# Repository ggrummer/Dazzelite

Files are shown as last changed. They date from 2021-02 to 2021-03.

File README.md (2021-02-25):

# Dazzelite
Dazzelite is an easy to build project that uses a ring of tri-color LED lights, controlled by an FPGA, using a few simple instructions, to create different patterns of light. It can be built on a breadboard or in a beautiful case.

A video introduction can be seen at the following link:
https://vimeo.com/516437596

The "Documents" directory contains all the guides for building and using Dazzelite.

The "Dazz12" directory contains all the FPGA code.

The "EAGLE" directory contains the schematic, parts list and board design.

The "BreadBoardSchematic" contains the schematic for a simple breadboard version.

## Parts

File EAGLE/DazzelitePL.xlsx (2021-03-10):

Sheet: Main Assy
Dazzelite Mechanical Assembly
Description | Qty | Manufacturer | Part Number | Distributer | Cost
Neopixel Ring 24 LEDs | 1 | Adafruit | 1586 | Digi-Key | 16.95
Case | 1 | Serpac | 232C,BK | Digi-Key | 12.63
Supports for Ring | 4 | Essentra | SP1-12-01 | Digi-Key | 2.32
9V Battery Connector | 1 | Keystone | 235-M | Digi-Key | 0.74
9V Battery | 1 | Any |  |  | 2.00 | Approximate
Screws, #4 x 1/4" | 4 | Serpac | 6004 | Digi-Key | 1.36
PCB Bare | 1 |  |  |  | 13.00 | Approximate
PCB Parts | 1 |  |  |  | 33.53
Total |  |  |  |  | 82.53

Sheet: PCB Parts
Dazzelite PCB Parts With Upduino Rev 3.0 Board and Other Components
Description | Ref Des | Qty | Manufacturer | Part Number | Distributer | Cost
Cap 0.1uF, 50V X7R, Radial | C1, C4, C5 | 3 | Kemet | C326C104K5R5TA | Digi-Key | 0.66
Cap 100uF, 25V, Alum, Radial | C2, C3 | 2 | Kemet | ESK107M025AE3AA | Digi-Key | 0.40
Diode, Schottky, Axial, 1A, 20V | D1 | 1 | MCC | 1N5817-TP | Digi-Key | 0.32
DC/DC-Converter 5V, 1A, SIP3 | DC1 | 1 | Traco Power | TSR 1-2450 | Digi-Key | 6.14
Res 36K, 1%, 1/4W, Mini | R1 | 1 | Stackpole | RNMF14FTC36K0 | Digi-Key | 0.10
Res 62K, 1%, 1/4W, Mini | R2 | 1 | Stackpole | RNMF14FTC62K0 | Digi-Key | 0.10
Switch, Pushbutton | S1 | 2 | TE | 1-1825027-1 | Digi-Key | 0.52
Switch, Slide, SPDT | S2 | 1 | E-Switch | EG2219 | Digi-Key | 0.89
Lattice iCE40UP5K FPGA Board | U1 | 1 | TinyVision | Upduino-V3.0 | Tindie | 24.00
Quad Bus Buffer, DIL14 | U2 | 1 | TI | SN74AHCT125N | Digi-Key | 0.40
Total |  |  |  |  |  | 33.53

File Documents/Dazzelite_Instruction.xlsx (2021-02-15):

Dazzelite Instruction Creator |  |  |  | Rev 0.1
By: Grant Grummer
Command | 1 | See below | One Byte
Address/Duration/Loops | 8 | See below | 6/8/8 Bits
Brightness/Qty/Control | 0 | See below | One Byte
Blue | 0 | 15 max | One Nibble
Green | 0 | 15 max | One Nibble
Red | 0 | 15 max | One Nibble
RF Instruction |  | 10800000 | 32 Bits
 | [31:28] | [27:20] | [19:12] | [11:0]
Instruction Description | Command Number | Address/Duration/ Loops/Hours On | Brightness/Qty/Hours Off/ Control | Color/Hours Delayed
Blackout display | 0
Delay 1 | 1 | Duration, 255 max, 0 is a random delay
Finish 3 | 2
Set one lite with random address and/or color | 3 | Address = 0 to 63, random = 64 | Brightness | Red=0 current
 |  |  |  | Red=1 new 4
Set one lite | 4 | Address, 0 to 63 | Brightness | Color
Chase (lites rap around) | 5 | Offset size [25:20] 2 | 0 = decrement lite offset,
 |  |  | 1 = increment lite offset,
 |  |  | 2 = zero lite offset
Left to right & right to left | 6 | Qty of lites [22:20] 6 | Brightness
Fade in & out | 7 | Lower Limit [25:24] | 0 = disable fading,
 |  | Upper Limit [23:22] | 1 = enable fading
 |  | Speed Up [21:20]
Loop the last x number of commands | 8 | Number of loops, 255 for infinite loop | Qty of commands = loop command line number - start command number. 255 max commands.
Set random color palette | 9 | Color number 0 to 15 |  | Color
Reserved | 10
Rainbow colors | 11 |  | 0 = disable
 |  |  | 1 = enable
 | 12
Auto Timeout 5 | 13 | Hours on: 31 max, 0 always on (default) | Hours off: 31 max, 0 once off stay off (default) | Hours delayed (off): 31 Max, 0 (default)
 | 14
 | 15
 |  | [11:8] | [7:4] | [3:0]
Colors In Instructions 4 & 9 |  | Blue | Green | Red
Notes
1 | Duration: | 255 max times = 5.12 mSeconds, A duration of 8 is fast
2 | For backwards compatability, an offset size of 0 = 1. All others = number entered
3 | All instruction sets must end with a finish command
4 | Uses random color palette in instruction 9
5 | Setup before issuing the display instruction set
6 | 1 to 8 lites per side

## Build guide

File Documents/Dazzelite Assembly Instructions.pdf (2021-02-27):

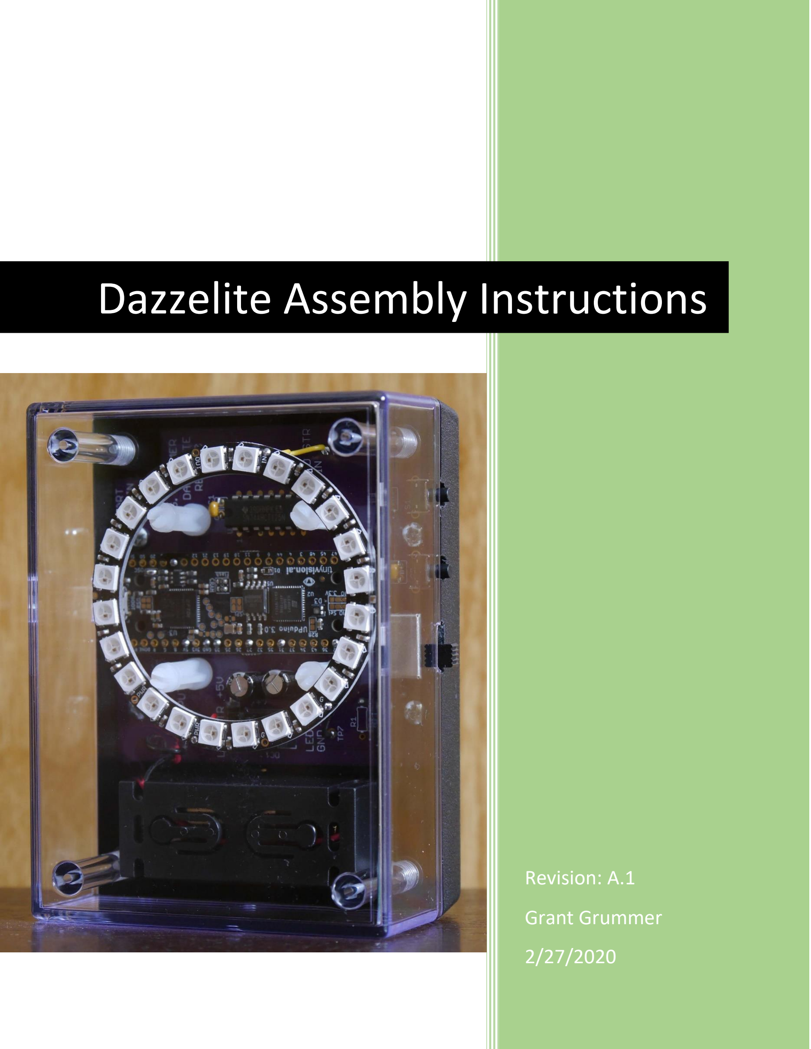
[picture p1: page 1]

## Grant Grummer

2/27/2020

# Dazzelite Assembly Instructions

## Revision: A.1

## Dazzelite Assembly Instructions

## Table of Contents

## Introduction

These instructions cover how to build a Dazzelite using a custom PCB installed into a beautiful case. The case (listed in the DazzelitePL spreadsheet parts list) has a plastic transparent top and an opaque bottom. It is assumed that all the parts, listed in the Dazzelite parts list, have been acquired before starting this assembly process.

## Tools required

The following list of tools are needed to build a Dazzelite:

- Soldering iron
- Solder
- Drill
- 3/16” drill bit (an optional small ~3/32” bit is helpful for drilling a pilot hole first)
- Philips screwdriver, #1
- Masking tape (optional but highly recommended)
- Wire cutters/strippers
- Small pliers
- Hobby knife (like an X-Acto knife)

## PCB Assembly Instructions

Only through hole parts are used in Dazzelite in order to make the PCB assembly easy to construct.

1. The UPduino board will need to be reworked before it can be used. It’s easier to do this rework before installing it onto the Dazzelite PCB. The rework involves the following two steps.
a. Apply a blob of solder across the OSC solder jumper
b. Highly recommend desoldering and removing LED D1. It distracts from the ring display.

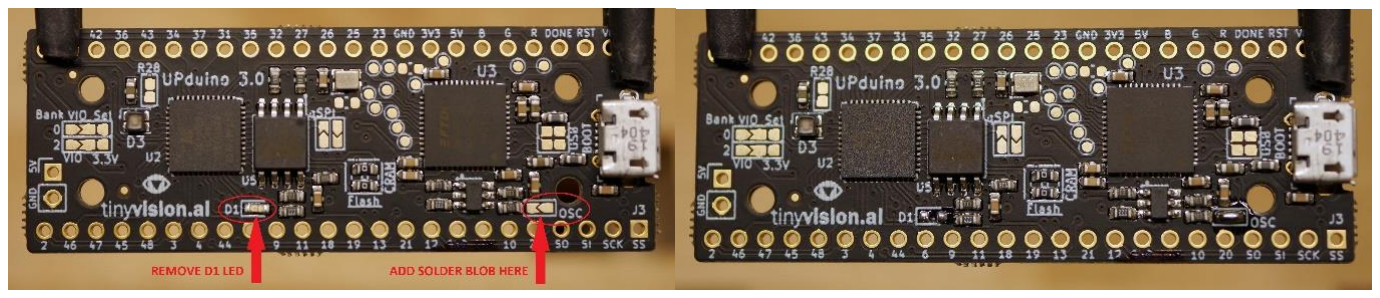
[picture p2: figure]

2. Insert the supports for the LED ring after all components have been soldered to the PCB
3. Break off 2 sets of 2 pins from the headers supplied with the UPduino
a. One set is used to for the 5V and GND pins furthest from the USB connector
b. The second set is used for TP3 and TP4 on the PCB
4. Place the headers on the PCB and the UPduino on the headers
a. None of the 8 pins on either side furthest from the USB connector, need to be connected to the PCB
b. All the other pins on the UPduino do not need to be soldered to the PCB (refer to schematic), but they can if desired.
c. All 5V and GND pins should be soldered to the PCB (including the ones furthest from the USB connector)
5. Solder all components to the component side of the PCB, except the LED ring which is placed above the PCB on supports (in the following steps)

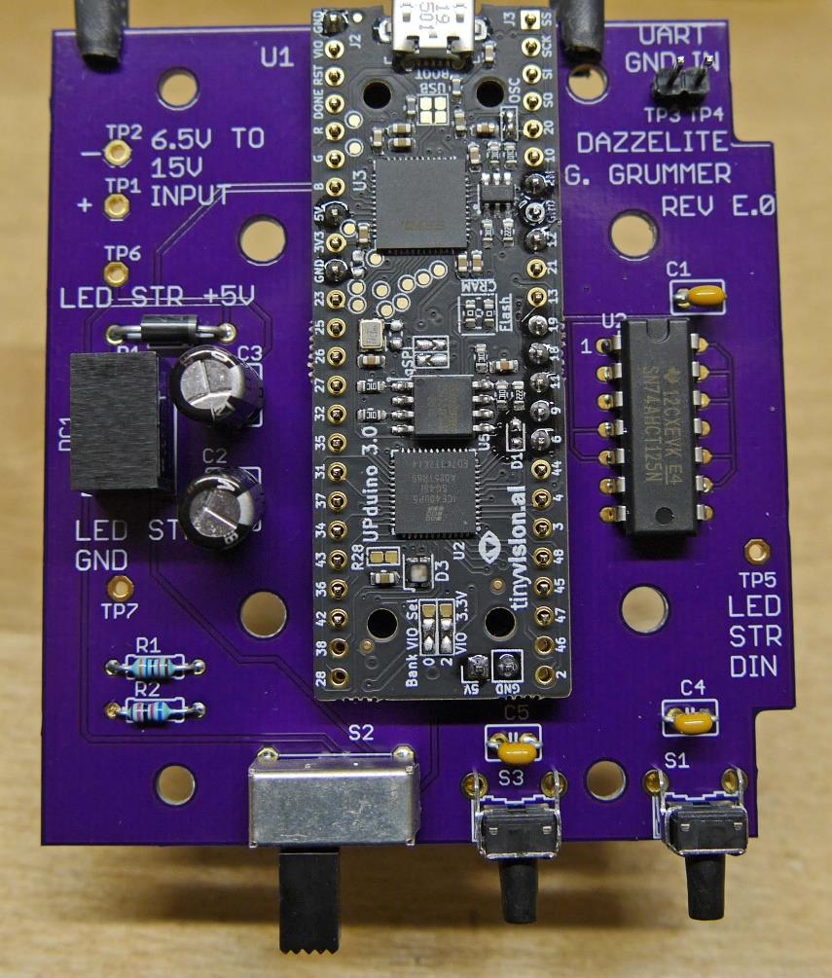
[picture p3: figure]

6. Rotate the LED ring so that the “IN” and “OUT” holes on the ring are the same distance to the edge of the PCB
7. Place ring onto the supports

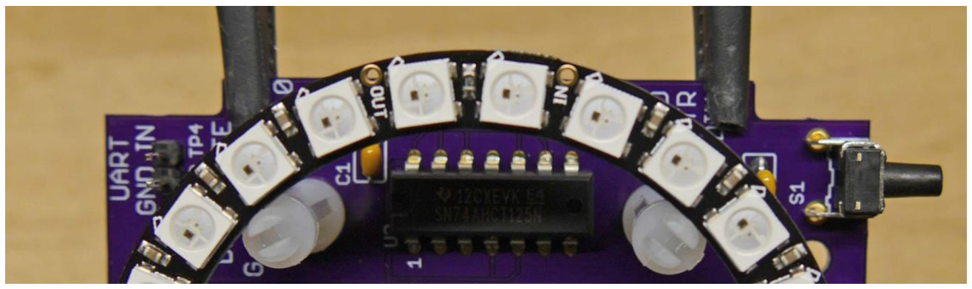
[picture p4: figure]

8. Solder the following 1-inch long wires from PCB to ring
a. TP5 on the PCB to IN on the ring
b. TP6 on the PCB to PWR on the ring
c. TP7 on the PCB to G on the ring
9. Do not attach the battery wires yet, it will be done in a later section

## Case Cutouts

These instructions are from the prospective of the 9V battery part of case up and looking into the case. The cutout for the USB is on the right side and the cutouts for the switches are on the left side.

To avoid scratching the top (transparent) section, put masking tape on the outside of it. Cover the whole top and the top two thirds of the sides.

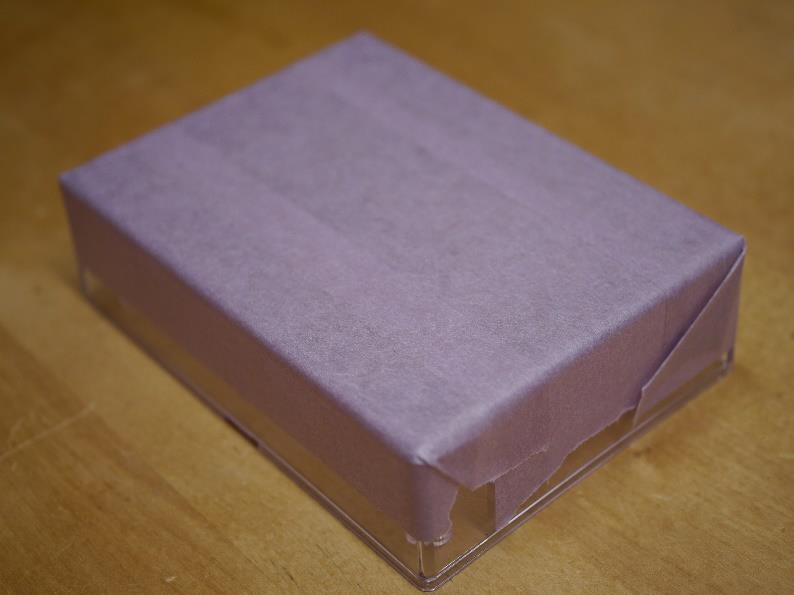
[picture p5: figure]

### Bottom (Opaque) Drilling and Cutouts

The top and bottom sections should not be attached.

All drill holes are located 5/8” from the bottom of the case.

The following table lists the locations of the drill holes from the side opposite the battery.

Part

From Case Side
Opposite Battery
S1 PB SW Location | 13/16
S3 PB SW Location | 1 & 7/16
S2 Slide SW Location | 1 & 15/16 and 2 & 3/16
USB Location | 1 & 5/8 and 1 & 13/16

Table 1: Drill Hole Locations

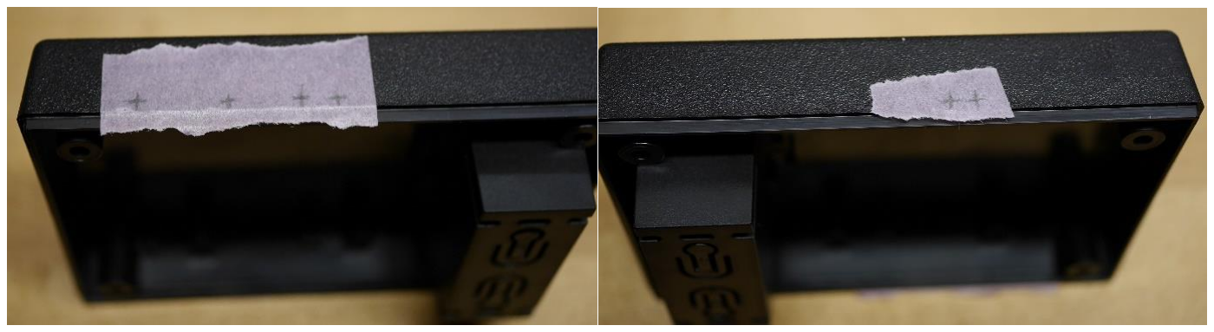
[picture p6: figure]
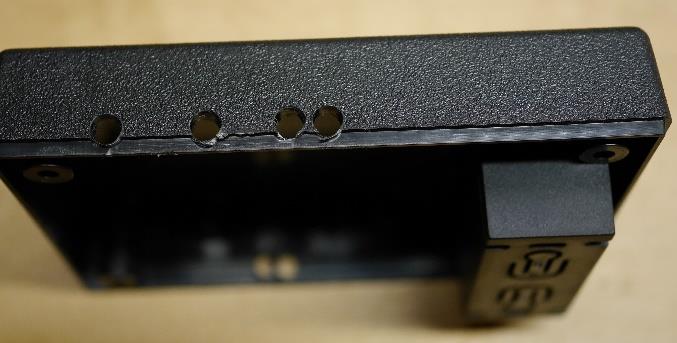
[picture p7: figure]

After the holes are drilled, make slots from the holes by cutting away the material from the side of the holes to the top on the bottom section of the case. Also cut away the material between the S2 (slide switch) holes and the USB holes.

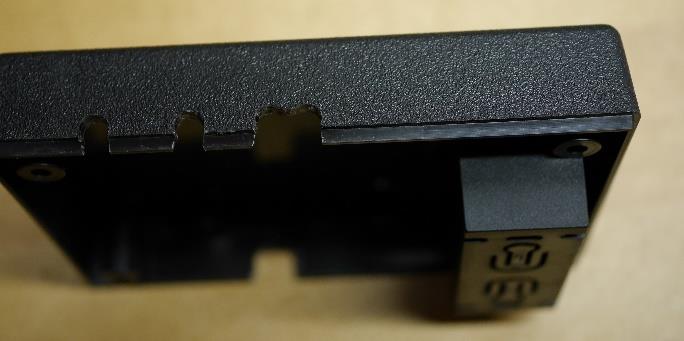
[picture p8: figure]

### Top (Transparent) Case S2 and USB Cutouts

Temporarily place the top and bottom sections together. The manufacturing plastic insertion dot side of the top section should align with the battery holder side of the case.

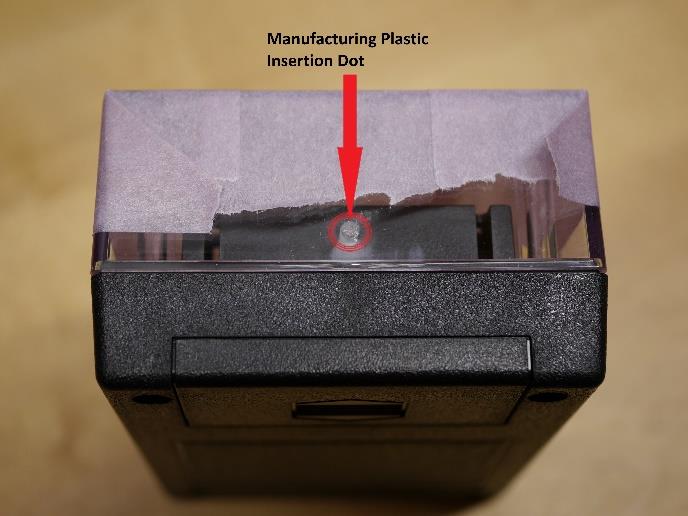
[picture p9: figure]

Mark (with the utility knife) where bottom section cutout for the S2 and USB cutouts meets the top section. There should now be 2 marks on each side. Separate the top and bottom sections. In each mark, cut down 0.1" to the thicker part of the top section. Cut away the thinner part (of the case) between the 2 marks on each side.

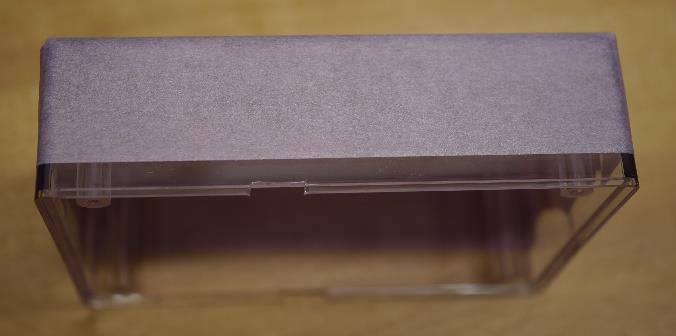
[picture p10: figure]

## Connecting Battery Wires

Temporary place the assembled PCB in the bottom section of the case. The battery wires go through the battery holder nearest to the “6.5V TO 15V INPUT” text on the PCB. The battery connector is placed at the opposite end of the battery holder.

Lift the assembled PCB so the battery wires can be soldered onto the board. The red (positive) wire connects to TP1 and the black (negative) wire connects to TP2.

## Assembly Note

Unfortunately, the UPduino board was built with the USB connector recessed into the PCB. This makes it difficult to access the connector through the case. So, just prior to screwing the PCB into the case, gently push the PCB towards the USB slot and hold it there. Now screw the board into the case. This helps get the USB connector closer to the case.

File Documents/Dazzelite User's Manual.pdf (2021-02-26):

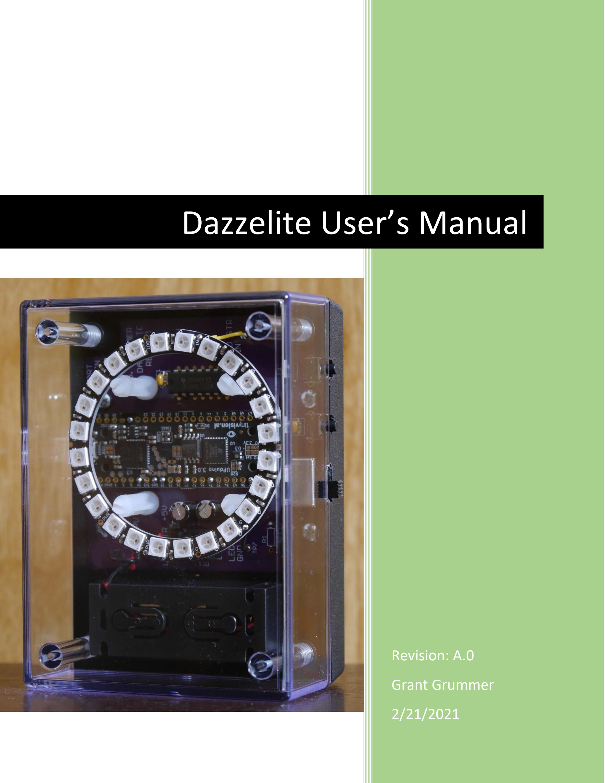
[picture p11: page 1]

## Grant Grummer

2/21/2021

# Dazzelite User’s Manual

## Revision: A.0

## Dazzelite User’s Manual

## Table of Contents

## Introduction

Welcome to the Dazzelite User’s Manual. Dazzelite can be built in many ways. One can build a version on a breadboard, a perfboard or a custom PCB. The perfboard and custom PCB versions can be mounted into a case, making the unit portable. This document is written for the custom PCB version, mounted into a beautiful, portable case with a built-in battery compartment.

Dazzelite uses a tri-color LED ring to produce different light displays. Dazzelite is programmable, so the displays are only limited by your imagination. No previous software knowledge is required. A set of default light displays along with an introduction to Dazzelite can be viewed at the following link:

https://vimeo.com/516437596

A small set of display specific instructions are used to create different display patterns. There are up to 16 possible instructions. Not all of these instructions are defined at the time of this writing. These are available for those who wish to augment the functionality of this project.

The design contains all the electronic hardware needed to drive the LED ring. The brain of the hardware is a Lattice iCE40 Ultra Plus 5K FPGA (Field Programmable Gate Array). It, along with programming and other support logic, is on the UPduino v3.0 (https://www.tindie.com/products/tinyvision_ai/upduino-v30-low-cost-lattice-ice40-fpga-board/?pt=ac_prod_search) low cost daughter board. It’s mounted onto the Dazzelite board. The Dazzelite board also contains switches, power supply and interface hardware. Dazzelite can be powered from the micro USB connector on the daughter board or an external source.

Dazzelite is controlled via three switches. The power slide switch enables/disables power from the external source or enables/disables the FPGA if powered from micro USB connector. The upper pushbutton switch selects one of four display pattern instruction sets. Each set can have up to 256 instructions. The lower pushbutton switch selects different brightness levels.

## Dazzelite Design Environment

In order to program Dazzelite, one must first setup a design environment. Refer to the “Dazzelite Installation and Setup” document for instruction on how to set it up. The rest of this document assumes this setup has been completed.

## Building the Design

The Lattice Radiant design environment is used to build the design. A full build is performed by clicking on the “Run All” triangle. The boxes to the right of the “Run All” triangle all turn green (with a check mark) once the design has been built. See Figure 1.

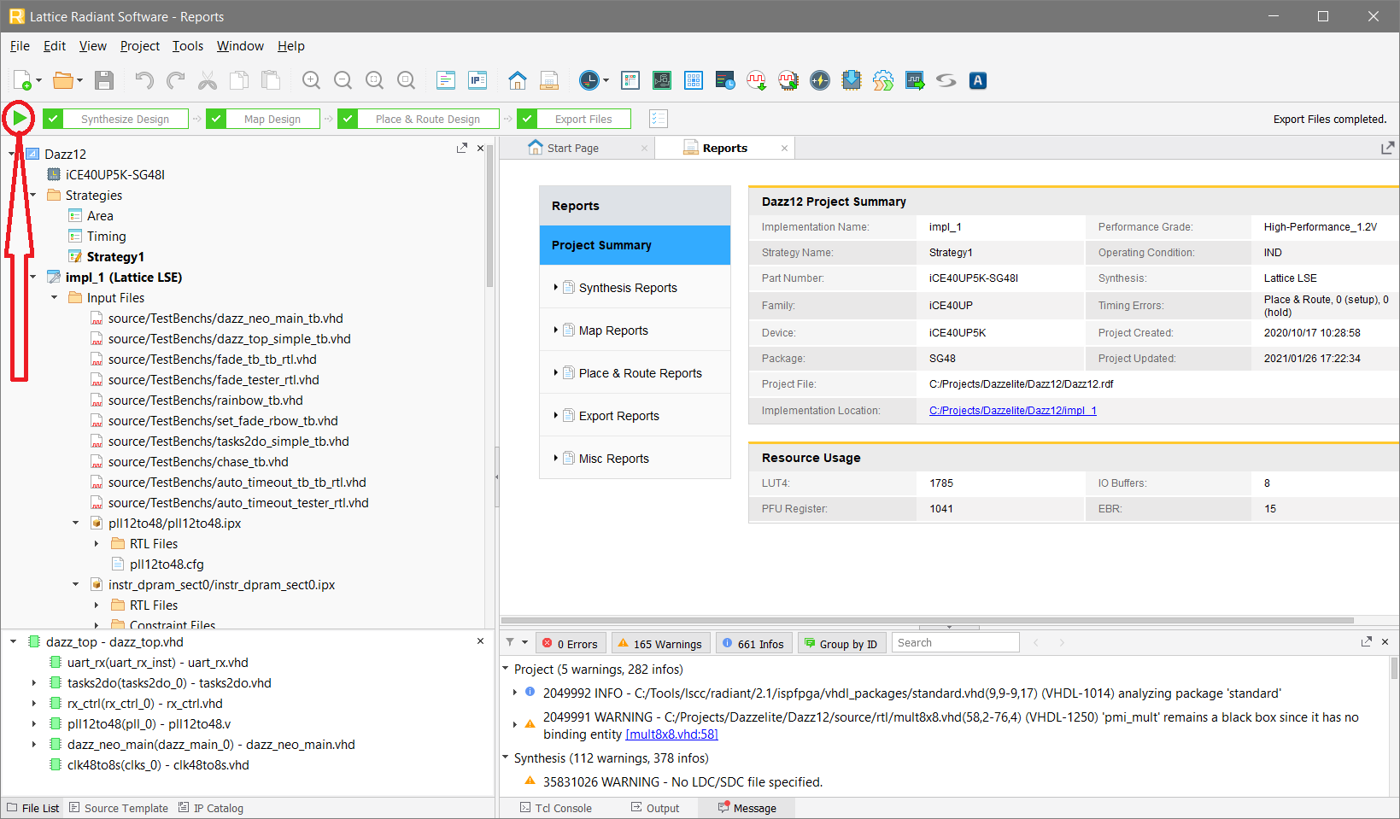
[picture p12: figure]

Figure 1: Run All

## Custom Displays

A great way to get started with making your own custom displays is to build new display instruction sets. One doesn’t need to know anything about FPGAs or software to do this. Use the supplied “Dazzelite_Instruction” spreadsheet to create each instruction. Use a text editor to combine the new instructions into a set of instructions. Refer to the supplied example display instruction sets, in the “Patterns” folder, to see how this looks. Remember to end each instruction set with the Finish instruction!

There are 4 memories in Dazzelite, each contain one display pattern. They are selected via the pattern pushbutton switch. Each memory can be loaded with a new pattern by double clicking on inst_dpram_sect0, 1, 2 or 3 as shown in Figure 2.

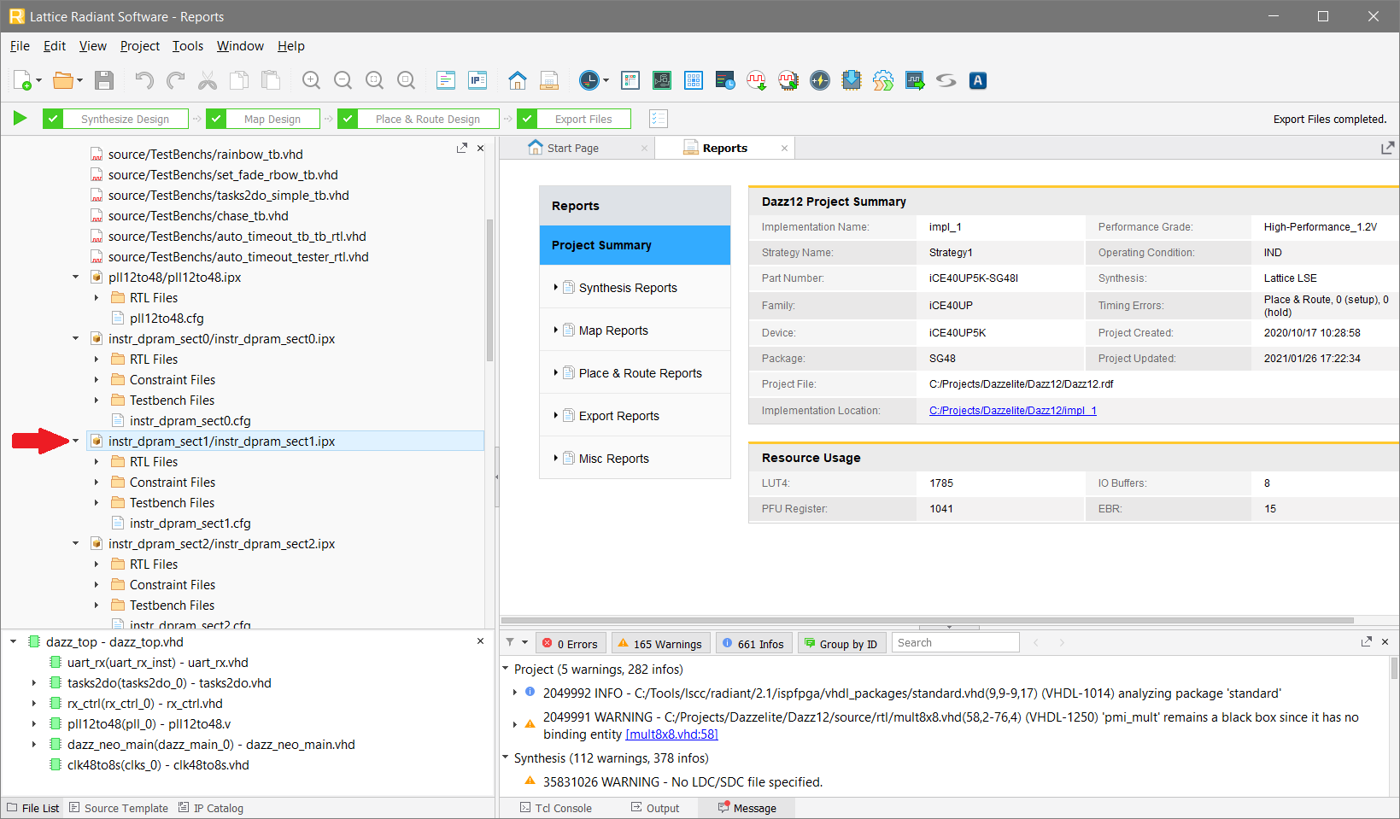
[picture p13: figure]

Figure 2: Changing Display Patterns

Replace the current instruction set with your new instruction set by clicking on “…” and navigating to that instruction as highlighted in Figure 3.

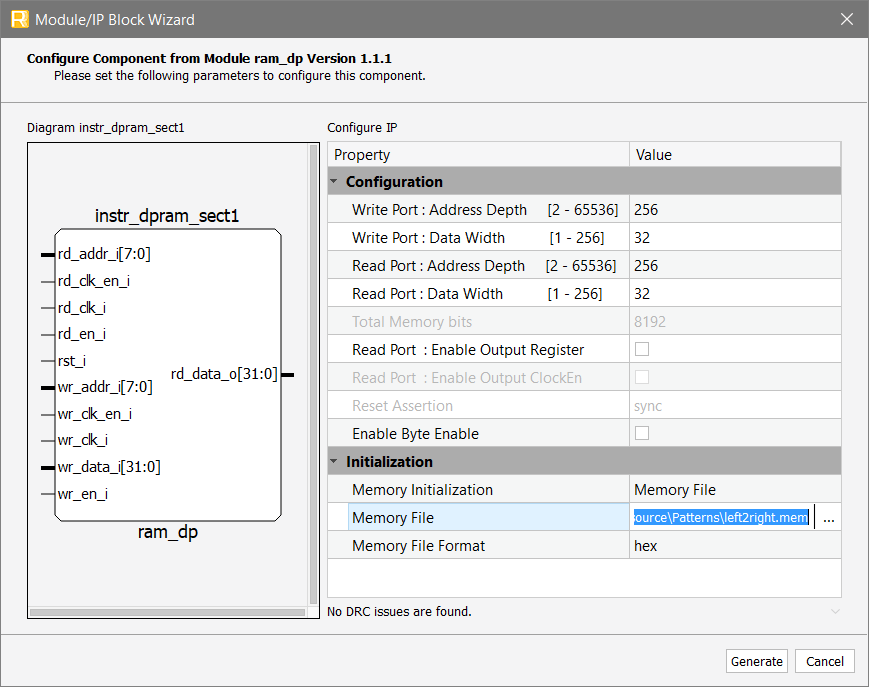
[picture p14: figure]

Figure 3: Replacing Display Pattern

Click in the “Generate” button (at the bottom of the window) to replace the display pattern. After that completes, re-build the design as outlined in the Building the Design section.

## Programming Dazzelite

Dazzelite can be programmed from the Radiant program or via a standalone programmer.

### Programmer Access Through Radiant

From Radiant, click on the programming icon as shown in Figure 4.

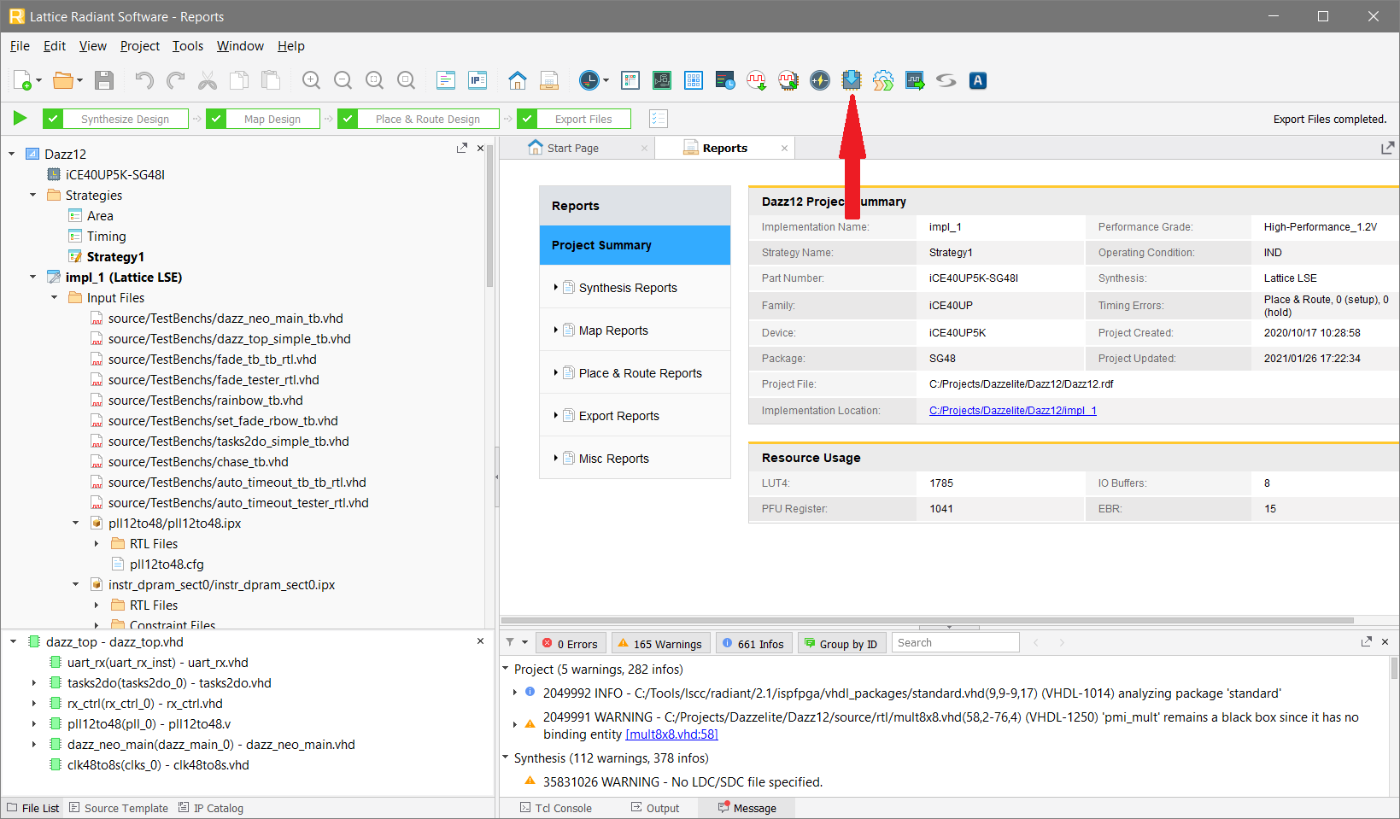
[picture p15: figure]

Figure 4: Programming Icon

### Standalone Programmers

There are many programmers that can be used to program Dazzelite. One is the Radiant Programmer Standalone (https://www.latticesemi.com/Products/DesignSoftwareAndIP/FPGAandLDS/Radiant) and another is the Diamond Programmer Standalone. (http://www.latticesemi.com/en/Products/DesignSoftwareAndIP/ProgrammingAndConfigurationSw/Programmer.aspx) They’re both very similar.

### Programming Steps

The following steps can be used with the Radiant Programmer (either via Radiant or standalone) to program Dazzelite. The Diamond Programmer steps may be slightly different.

1. Connect the micro USB port on the UPDuino v3.0 to your PC
2. Open the Radiant Programmer
3. Click `Detect Cable` then `OK`
4. After scanning, select `Generic JTAG Device` and `Select iCE40 UltraPlus`
5. Under `Device` click iCE40UP3K and change it to iCE40UP5K
6. Under `Operation` double click `Fast Program` and change `Target Memory: ` to `External SPI Flash Memory`
7. Select your `*.hex` programming file under `Programming file`.
8. Configure the following `SPI Flash Options`
a. Winbond
b. W25Q32JV
c. 208mil 8-pin SOIC
9. Click `Load from File` under `SPI Programming` to get load size
10. Click OK
11. Click `Run` -> `Program Device`

## Instructions

The Dazzelite_Instruction spreadsheet provides an easy way to create instructions. It allows instructions to be build using decimal number and automatically provides the hexadecimal value (of the instruction) needed by the FPGA. Optionally, a detailed look at each bit, in each instruction, is provided in the rest of this section.

As previously noted, there are up to 16 possible instructions. Some are specifically tailored for the RGB LED ring. Instructions are 32-bits long. All instructions start with a command. Some commands are followed by additional fields. A detailed description of each instruction is presented in the following sections. Note all bits of the instructions are zeroed at powerup unless otherwise noted.

### Instruction 0: Blackout Display

Blackouts the entire display.

31 | 28 | 27 | 0
CMD0 | Unused | Unused | Unused | Unused | Unused
Bits | Name | Function
[31:28] | CMD0 | Blackouts all the LEDs in the string(s). All bits must be zero.
[27:0] | Unused | Not defined

### Instruction 1: Delay

Adds a programmable time delay. Each additional count adds 5.12 mSeconds. The maximum count is 255 (0xFF). A count a zero creates a random delay.

31 | 28 | 27 | 20 | 19 | 0
CMD1 | DLY | Unused | Unused | Unused | Unused
Bits | Name | Function
[31:28] | CMD1 | Programmable delay. Value = 1
[27:20] | DLY | Delay count. Max = 255 (0xFF). All zeros create a random count.
[19:0] | Unused | Not defined

### Instruction 2: Finish

All instruction sets must end with a finish command!

31 | 28 | 27 | 0
CMD2 | Unused | Unused | Unused | Unused | Unused
Bits | Name | Function

[31:28] | CMD2 | Informs the FPGA that the present instruction set is finished. Value = 2
[27:0] | Unused | Not defined

### Instruction 3: Set Random LED

Used to set one LED at a random location/address and/or color. The random color is selected from the 16 colors in the color palette (see Instruction 9: Set Color Palette).

31 | 28 | 27|26| 25 | 20 | 19 | 12 | 11 | 1 | 0
CMD3 | U | R | | ADDR | BRITE | Unused | Unused | Unused|N
Bits | Name | Function
[31:28] | CMD3 | Sets one LED. Value = 3
[27] | U | Unused, not defined
[26] | R | Random LED address 0 = bits [25:0] specify address of LED 1 = random LED address generated
[25:20] | ADDR | Specific LED address when [26] = 0. Values 0 to 63 (0x3F)
[19:12] | BRITE | Set the brightness of the LED. Values 0 to 255 (0xFF)
[11:1] | Unused | Not defined
[0] | N | 0 = use the same color as used in the last CMD3. That color was the one last selected from the color palette. 1 = use the next color in the color palette.

### Instruction 4: Set LED

Used to set one LED’s address and color.

31 | 28 | 27 26 | 25 | 20 | 19 | 12 | 11 | 8 | 7 | 4 | 3 | 0
CMD4 | U | | ADDR | BRITE | BLUE | GREEN | RED
Bits | Name | Function
[31:28] | CMD4 | Sets one LED. Value = 4
[27:26] | U | Unused, not defined
[25:20] | ADDR | Specific LED address. Values 0 to 63 (0x3F)
[19:12 | BRITE | Set the brightness of the LED. Values 0 to 255 (0xFF)
[11:8] | BLUE | Sets the amount of blue. Value 0 to 15 (0xF)
[7:4] | GREEN | Sets the amount of green. Value 0 to 15 (0xF)
[3:0] | RED | Sets the amount of red. Value 0 to 15 (0xF)

### Instruction 5: Chase

Adds an offset to all LED addresses. Increments or decrements that address along with their brightness and color. The offset wraps around at maximum numbers of LEDs per string.

31 | 28 | 27 26 | 25 | 20 | 19 | 14|13|12 | 11 | 0
CMD5 | U | | SIZE | Unused | | Z | ID | Unused | Unused | Unused
Bits | Name | Function
[31:28] | CMD5 | Increments or decrements every LED’s address by the offset size. Value = 5
[27:26] | U | Not defined
[25:20] | SIZE | Offset size. A size of 0 = 1. All others = number entered
[19:14] | Unused | Not defined
[13] | Z | 0 = do not zero LEDs address offset 1 = zeros LEDs address offset (ID value ignored)
[12] | ID | 0 = decrement offset 1 = increment offset
[11:0] | Unused | Not defined

### Instruction 6: Left to Right and Right to Left

Two strings of colors start at the top of the display and make their way to the bottom then back up to the top. As they merge (at the bottom), They are added together and the resulting color is displayed.

31 | 28 | 27 | 23 | 22 | 20 | 19 | 12 | 11 | 0
CMD6 | Unused | | QTY | BRITE | Unused | Unused | Unused
Bits | Name | Function
[31:28] | CMD6 | Runs the algorithm. Value = 6
[27:23] | Unused | Not defined
[22:20] | QTY | Quantity of lights, 1 to 8 per side
[19:12] | BRITE | Set the brightness of the LED. Values 0 to 255 (0xFF)
[11:0] | Unused | Not defined

### Instruction 7: Fade In and Out

Fades all LEDs brightness. Increments and then decrements all LEDs brightness.

31 | 28 | 27 26|25 24|23 22|21 20 | 19 | 13|12 | 11 | 0
CMD7 | U | LLIM| ULIM| SPD | Unused | | EF | Unused | Unused | Unused
Bits | Name | Function
[31:28] | CMD7 | Increments or decrements every LED’s address by one. Value = 7
[27:26] | U | Unused, not defined
[25:24] | LLIM | Limits how low the brightness value can go
[23:22] | ULIM | Limits how high the brightness value can go
[21:20] | SPD | Speeds up the incrementing and decrementing
[19:13] | Unused | Not defined

[12] | EF | 0 = disable fading once decrement reaches its lowest value 1 = enables fading starting at its lowest value
[11:0] | Unused | Not defined

### Instruction 8: Loop

Loop the previous x number of instructions.

31 | 28 | 27 | 20 | 19 | 12 | 11 | 0
CMD8 | LOOPS | QTY | Unused | Unused | Unused
Bits | Name | Function
[31:28] | CMD8 | Repeats previous instructions. Value = 8
[27:20] | LOOPS | Sets the number of times a loop is executed. A value of 255 (0xFF) is a continuous loop.
[19:12] | QTY | Quantity of instruction to repeat. Subtract the start instruction from the loop instruction line number.
[11:0] | Unused | Not defined

### Instruction 9: Set Color Palette

Storage location for 16 definable colors. Used in conjunction with Instruction 3: Set Random LED. A set of predefined colors are loaded at powerup. Use this instruction to change them.

31 | 28 | 27 | 24 | 23 | 20 | 19 | 12 | 11 | 8 | 7 | 4 | 3 | 0
CMD9 | Unused | CNUM | Unused | BLUE | GREEN | RED
Bits | Name | Function
[31:28] | CMD9 | Sets one LED. Value = 9
[27:24] | Unused | Not defined
[23:20] | CNUM | Specific palette address. Values 0 to 15 (0xF)
[19:12] | Unused | Not defined
[11:8] | BLUE | Sets the amount of blue. Value 0 to 15 (0xF)
[7:4] | GREEN | Sets the amount of green. Value 0 to 15 (0xF)
[3:0] | RED | Sets the amount of red. Value 0 to 15 (0xF)

### Instruction 10 (0xA): Reserved

Do not use. It’s used in other versions of this project.

31 | 28 | 27 | 0
CMD10 | Unused | Unused | Unused | Unused | Unused
Bits | Name | Function
[31:28] | CMD10 | Reserved. Value = 10 (0xA)
[27:0] | Unused | Not defined

### Instruction 11 (0xB): Rainbow

Transitions through the 12-bit color spectrum.

31 | 28 | 27 | 13|12 | 11 | 0
CMD11 | Unused | Unused | |ER | Unused | Unused | Unused
Bits | Name | Function
[31:28] | CMD11 | Increments or decrements every LED’s address by one. Value = 11 (0xB)
[27:13] | Unused | Not defined
[12] | ER | 0 = disable the transitions 1 = enables the transitions
[11:0] | Unused | Not defined

### Instruction 12 (0xC): Reserved

Do not use. It’s used in other versions of this project.

31 | 28 | 27 | 0
CMD12 | Unused | Unused | Unused | Unused | Unused
Bits | Name | Function
[31:28] | CMD12 | Reserved. Value = 12 (0xC)
[27:0] | Unused | Not defined

### Instruction 13 (0xD): Automatic Timeout

Automatically turns the LEDs on and off according to the following settings. The instruction set in use before the time “off” will resume once the time “on” is attained. One should set this up before issuing display instructions.

31 | 28 | 27 | 25 | 24 | 20 | 19 | 17 | 16 | 12 | 11 | 5 | 4 | 0
CMD13 | Unused | | HON | Unused | | HOFF | Unused | Unused | HDLY
Bits | Name | Function
[31:28] | CMD13 | Sets one LED. Value = 13 (0xD)
[27:25] | Unused | Not defined
[24:20] | HON | Hours on. “0” is always on. Values 0 to 31 (0x1F)
[19:17] | Unused | Not defined
[16:12] | HOFF | Hours off. “0” is once off stay off. Value 0 to 31 (0x1F)
[11:5] | Unused | Not defined
[4:0] | HDLY | Hours delayed (off). Value 0 to 31 (0x1F)

### Instruction 14 (0xE): Unused

Available for a new instruction.

31 | 28 | 27 | 0
CMD14 | Unused | Unused | Unused | Unused | Unused
Bits | Name | Function
[31:28] | CMD14 | Unused but available. Value = 14 (0xE)
[27:0] | Unused | Not defined

### Instruction 15 (0xF): Unused

Available for a new instruction.

31 | 28 | 27 | 0
CMD15 | Unused | Unused | Unused | Unused | Unused
Bits | Name | Function
[31:28] | CMD15 | Unused but available. Value = 15 (0xF)
[27:0] | Unused | Not defined

## Code Base

The code base consists of mostly VHDL modules, some Verilog modules, instantiated and inferred IPs. There are 5 instantiated cores.

One instantiated core is a PLL (Phase Lock Loop). It’s used for creating a 48 MHz clock from the 12 MHz oscillator on the daughter board. A separate module divides the 48 MHz clock down to the 8 MHz and 800 kHz clocks used in the design. The majority of the design runs at 800 kHz.

The 4 remain cores are 256 x 32 memories. Each core holds an instruction set for a display pattern.

## Block Diagram of Dazzelite Code

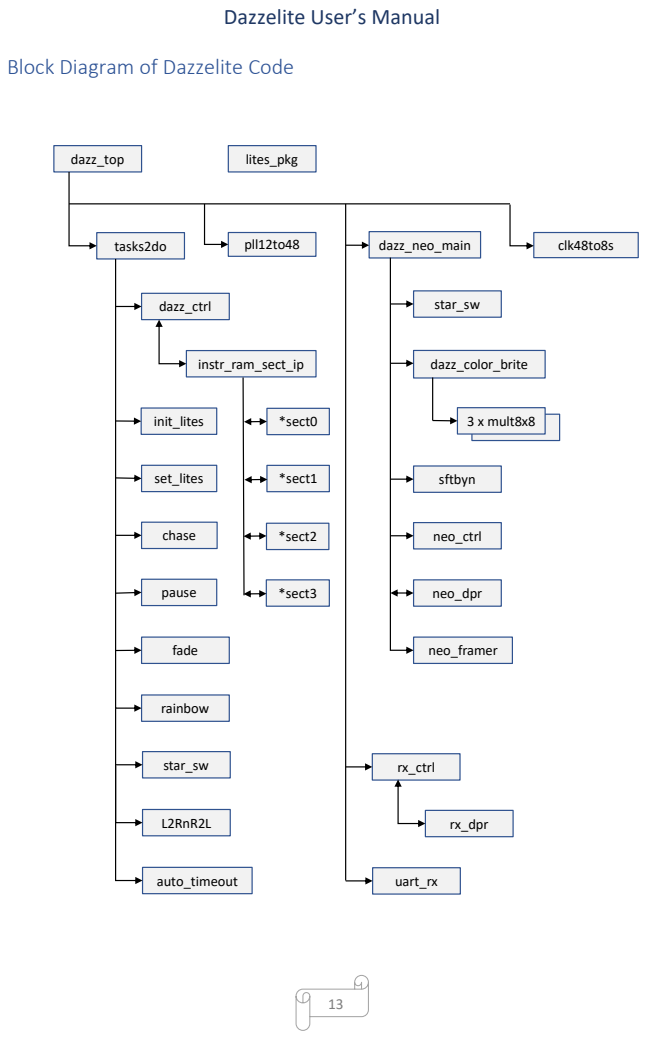
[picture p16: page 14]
chase; pause; fade; rainbow; set_lites; dazz_top; tasks2do; dazz_ctrl; instr_ram_sect_ip; init_lites; lites_pkg; pll12to48; dazz_neo_main; neo_ctrl; neo_dpr; neo_framer; uart_rx; star_sw; L2RnR2L; dazz_color_brite; 3 x mult8x8; auto_timeout; rx_ctrl; rx_dpr; sftbyn; clk48to8s; *sect0; *sect1; *sect2; *sect3

## UART

A UART can be used to temporarily download a new display pattern to Dazzelite. The pattern gets loaded into the first display’s memory. It’s remains in that memory until power is turned off.

The UART uses the following protocol.

- 9600 baud rate
- One start bit
- Eight hex data bits
- One stop bit

Each transfer consists of one bite. Four transfers are required to make one instruction. Multiple sets of four instructions, following each other, make up a Dazzelite instruction set.

The protocol has been used by an old Digi XBee wireless board. The newer boards “appear” to still support this protocol. This has not been tested with new boards.

By adding a wireless board to Dazzelite, one can use a remote wireless board to communicate with it. The UART pins are used to connect Dazzelite to the local wireless board. Digi’s XCTU software can be used with Digi XBee boards to remotely send a new display pattern.

Some UART programs support sending hex data, though it’s not common. These can be used to directly sent a new temporary display pattern to Dazzelite using a USB to serial (3.3V) cable.

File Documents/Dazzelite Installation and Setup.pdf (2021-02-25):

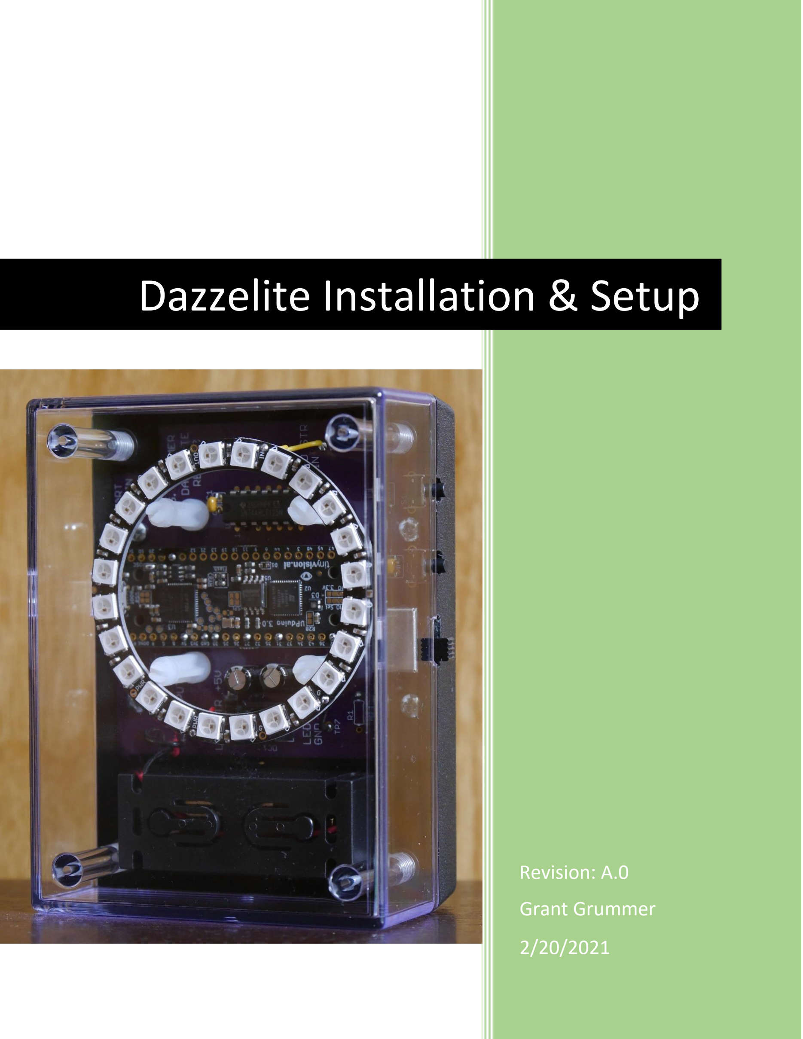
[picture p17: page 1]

## Grant Grummer

2/20/2021

# Dazzelite Installation & Setup

## Revision: A.0

## Dazzelite Installation & Setup

## Table of Contents

## Introduction

Welcome to the Dazzelite project setup. Whether you’re planning to build a version on a breadboard, a perfboard or a custom PCB, the follow information will help you on your way. This document covers Windows installations only.

## Installing Build Tools

The design was built using the Lattice Semiconductor Radiant platform. There are other tools one could use, but that would require significant changes to the supplied code. Radiant is free and is available on the Lattice website at:

http://www.latticesemi.com/Products/DesignSoftwareAndIP/FPGAandLDS/Radiant

You’ll find useful documentation on that web page. The Radiant Software Installation Guide document has important installation and license information. A license is required to run Radiant. The link to obtaining a license is also at the above website. Follow the license link. You’ll be asked to sign in to your account. If you don’t have one, you’ll need to create by selecting the “Create Account” link.

Once a license is obtained, download and install Radiant. When the “Select Component(s)” window opens, the only FPGA device you’ll need is the “Lattice iCE40UP”, though it’s ok to install more devices if desired.

## Download Dazzelite Files

The Dazzelite files are located in GitHub. In order to download the files, one clones the directories using “GitHub Desktop”. (https://desktop.github.com/) Once GitHub Desktop is installed, the Dazzelite project is located at:

https://github.com/ggrummer/Dazzelite

Place all the files and directories in a new directory. The design was built using the following root directory structure: “C:\Projects\Dazzelite”. It may be OK to use a different directory structure, but that hasn’t been tested.

## Building the Design for the First Time

Start the Radiant program. Double click on the “Open Project” icon. See Figure 1.

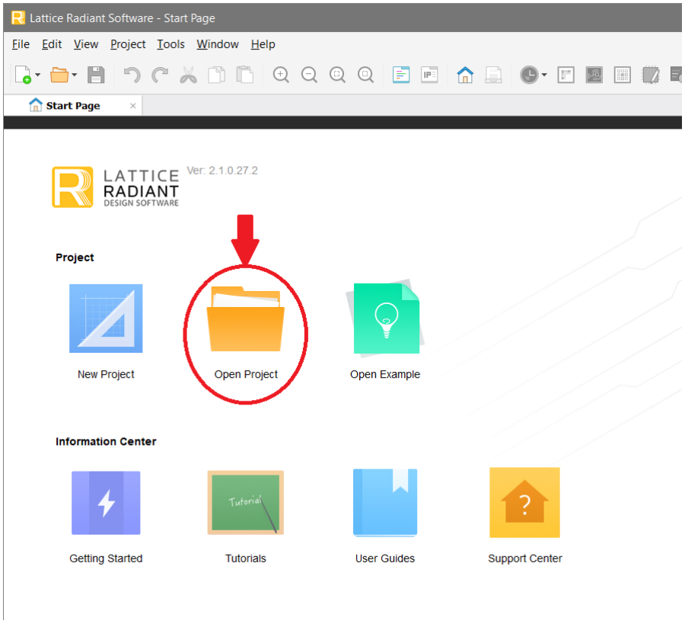
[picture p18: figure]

Figure 1: Open Project Window

Navigate to the “Dazz12” directory and select the “Dazz12.rdf” file. The Lattice Radiant Software main

window will open. Click on the “Run All” triangle. See Figure 2.


Figure 2: Lattice Radiant Software Window

The boxes to the right of the “Run All” triangle all turn green (with a check mark) once the design has been built.

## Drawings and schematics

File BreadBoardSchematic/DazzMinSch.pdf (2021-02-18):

A

A

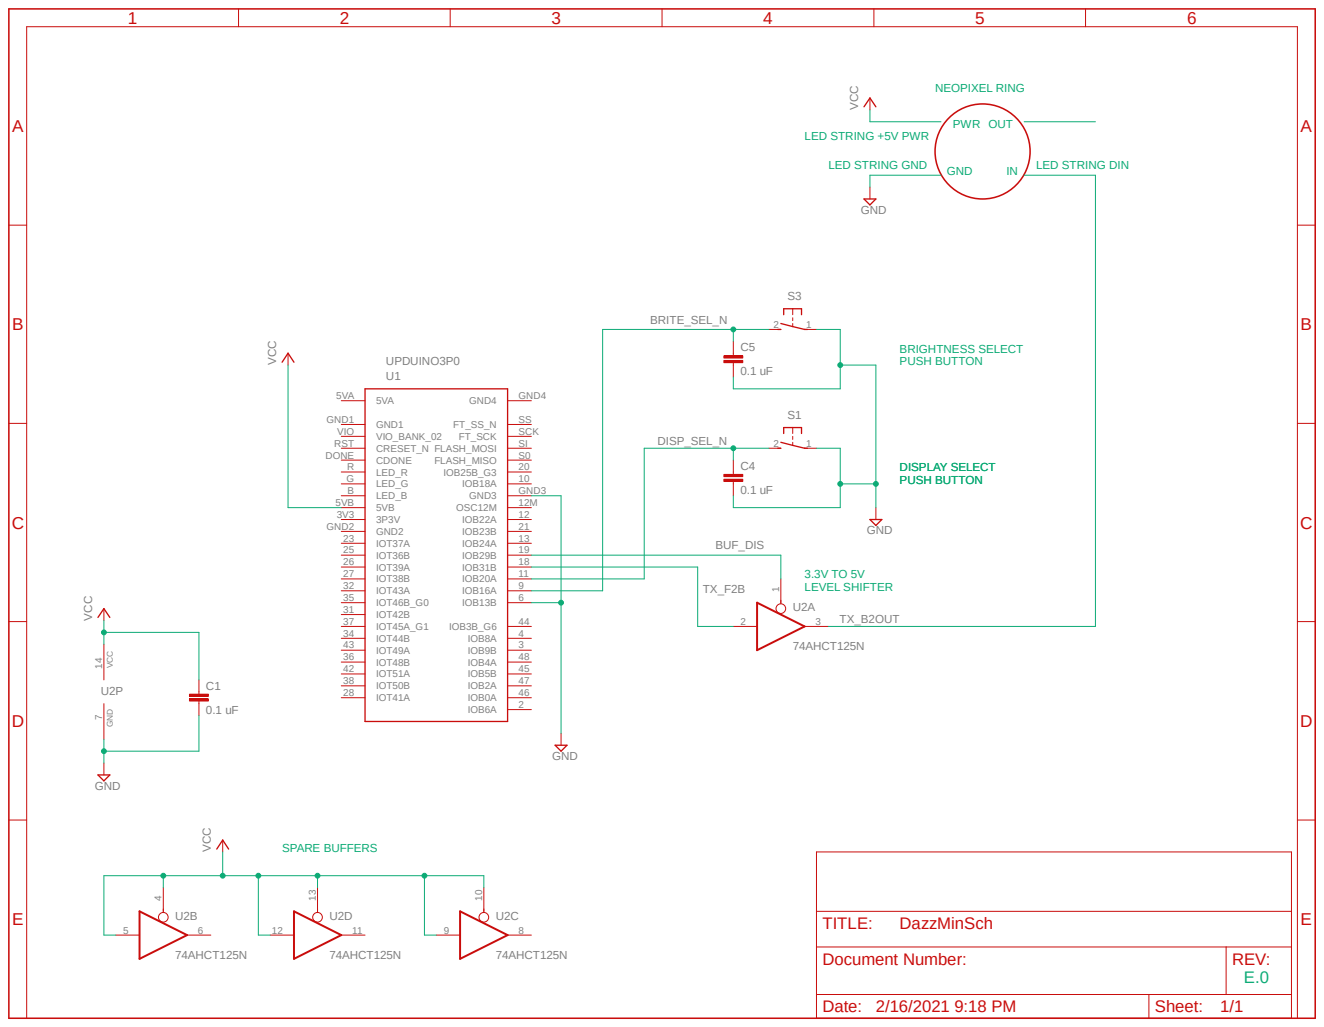
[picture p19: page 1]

LED STRING +5V PWR

Document Number: | REV: E.0

Date: 2/16/2021 9:18 PM | Sheet: 1/1

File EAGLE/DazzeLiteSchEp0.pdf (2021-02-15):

# TP6 TP7

# 4 S2

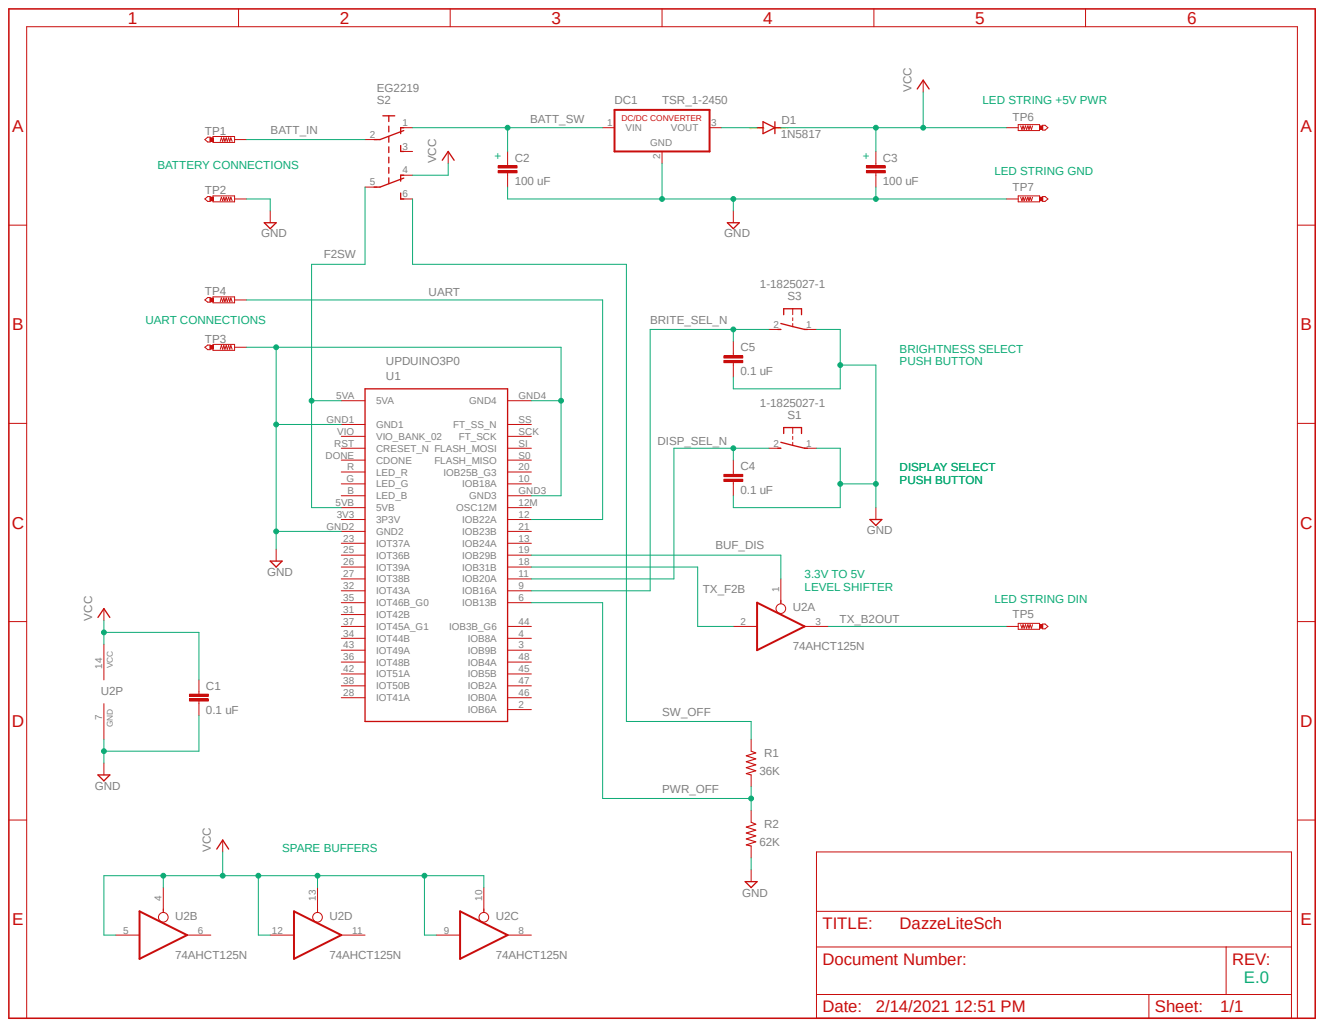
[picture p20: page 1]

Document Number: | REV: E.0

Date: 2/14/2021 12:51 PM | Sheet: 1/1

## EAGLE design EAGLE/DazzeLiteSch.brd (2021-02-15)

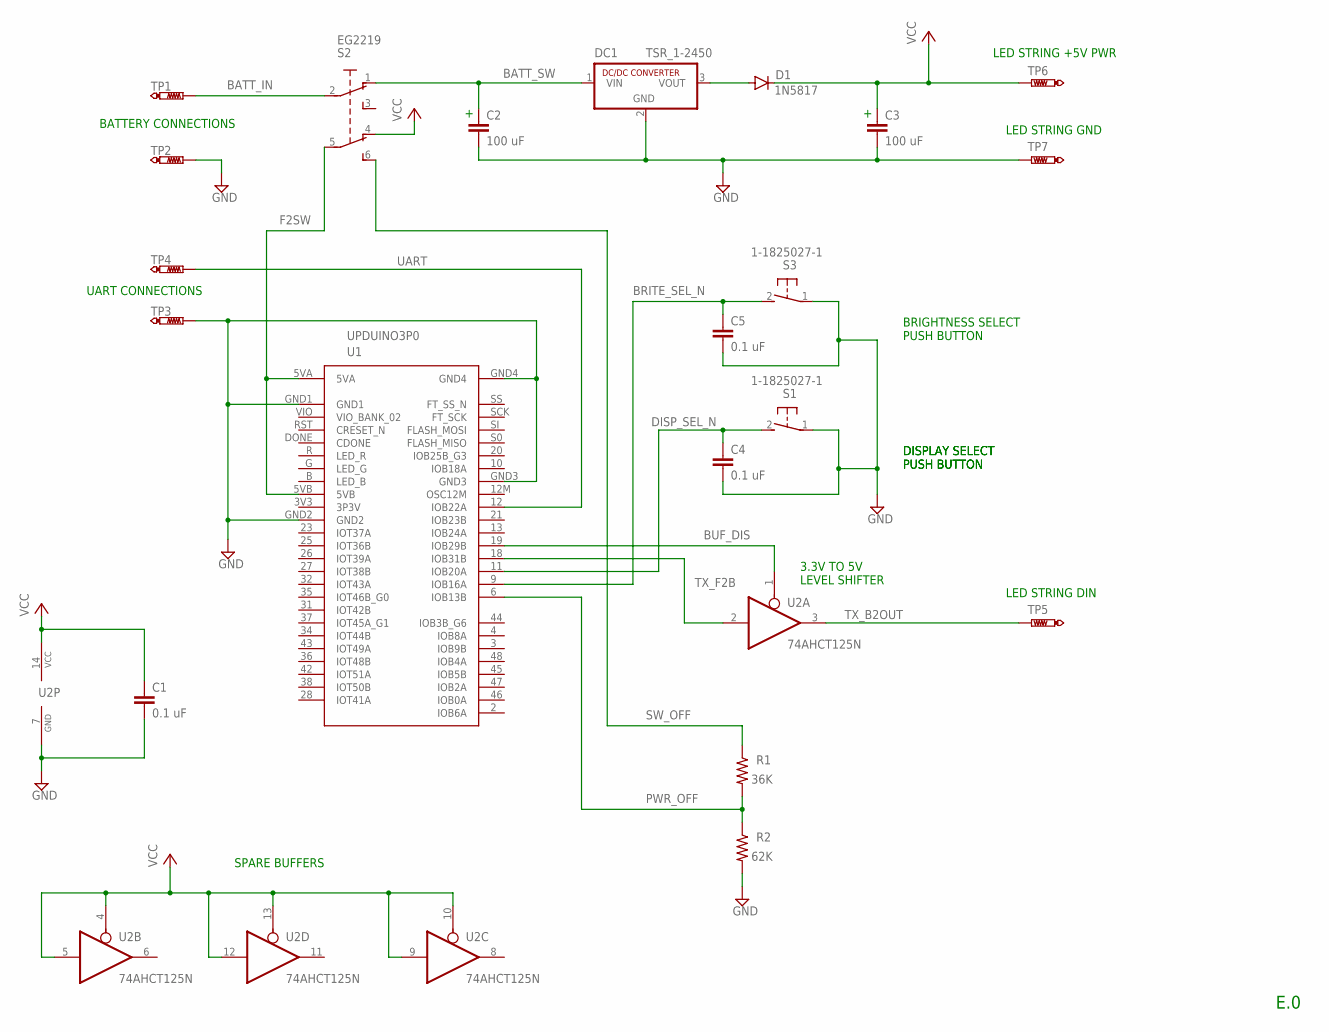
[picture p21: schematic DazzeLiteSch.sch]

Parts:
C1, C4, C5: 0.1 uF; C2.5-3
C2, C3: 100 uF; C2.5-6
D1: 1N5817; DO41-10
DC1: TSR_1-2450; SIP3
R1: 36K; 0204/7
R2: 62K; 0204/7
S1, S3: 1-1825027-1; B3F-31XX
S2: EG2219; DPDT157
TP1, TP2, TP3, TP4, TP5, TP6, TP7: PTR1PAD1-13; P1-13
U1: UPDUINO3P0
U2: 74AHCT125N; DIL14

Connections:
BATT_IN: S2.2, TP1.TP
BATT_SW: C2.1, DC1.1 (VIN), S2.1 (O)
BRITE_SEL_N: C5.1, S3.2 (S), U1.9 (IOB16A)
BUF_DIS: U1.19 (IOB29B), U2.1 (OE)
DISP_SEL_N: C4.1, S1.2 (S), U1.11 (IOB20A)
F2SW: S2.5 (P1), U1.5VA, U1.5VB
GND: C1.2, C2.2, C3.2, C4.2, C5.2, DC1.2 (GND), R2.2, S1.1, S3.1, TP2.TP, TP3.TP, TP7.TP, U1.GND1, U1.GND2, U1.GND3, U1.GND4, U2.7 (GND)
unnamed: D1.A, DC1.3 (VOUT)
PWR_OFF: R1.2, R2.1, U1.6 (IOB13B)
SW_OFF: R1.1, S2.6 (S1)
TX_B2OUT: TP5.TP, U2.3 (O)
TX_F2B: U1.18 (IOB31B), U2.2 (I)
UART: TP4.TP, U1.12 (IOB22A)
VCC: C1.1, C3.1, D1.C, S2.4 (O1), TP6.TP, U2.4 (OE), U2.5 (I), U2.9 (I), U2.10 (OE), U2.12 (I), U2.13 (OE), U2.14 (VCC)

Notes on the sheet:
LED STRING DIN
UART CONNECTIONS
BATTERY CONNECTIONS
LED STRING +5V PWR
LED STRING GND
E.0
DISPLAY SELECT PUSH BUTTON
3.3V TO 5V LEVEL SHIFTER
SPARE BUFFERS
BRIGHTNESS SELECT PUSH BUTTON

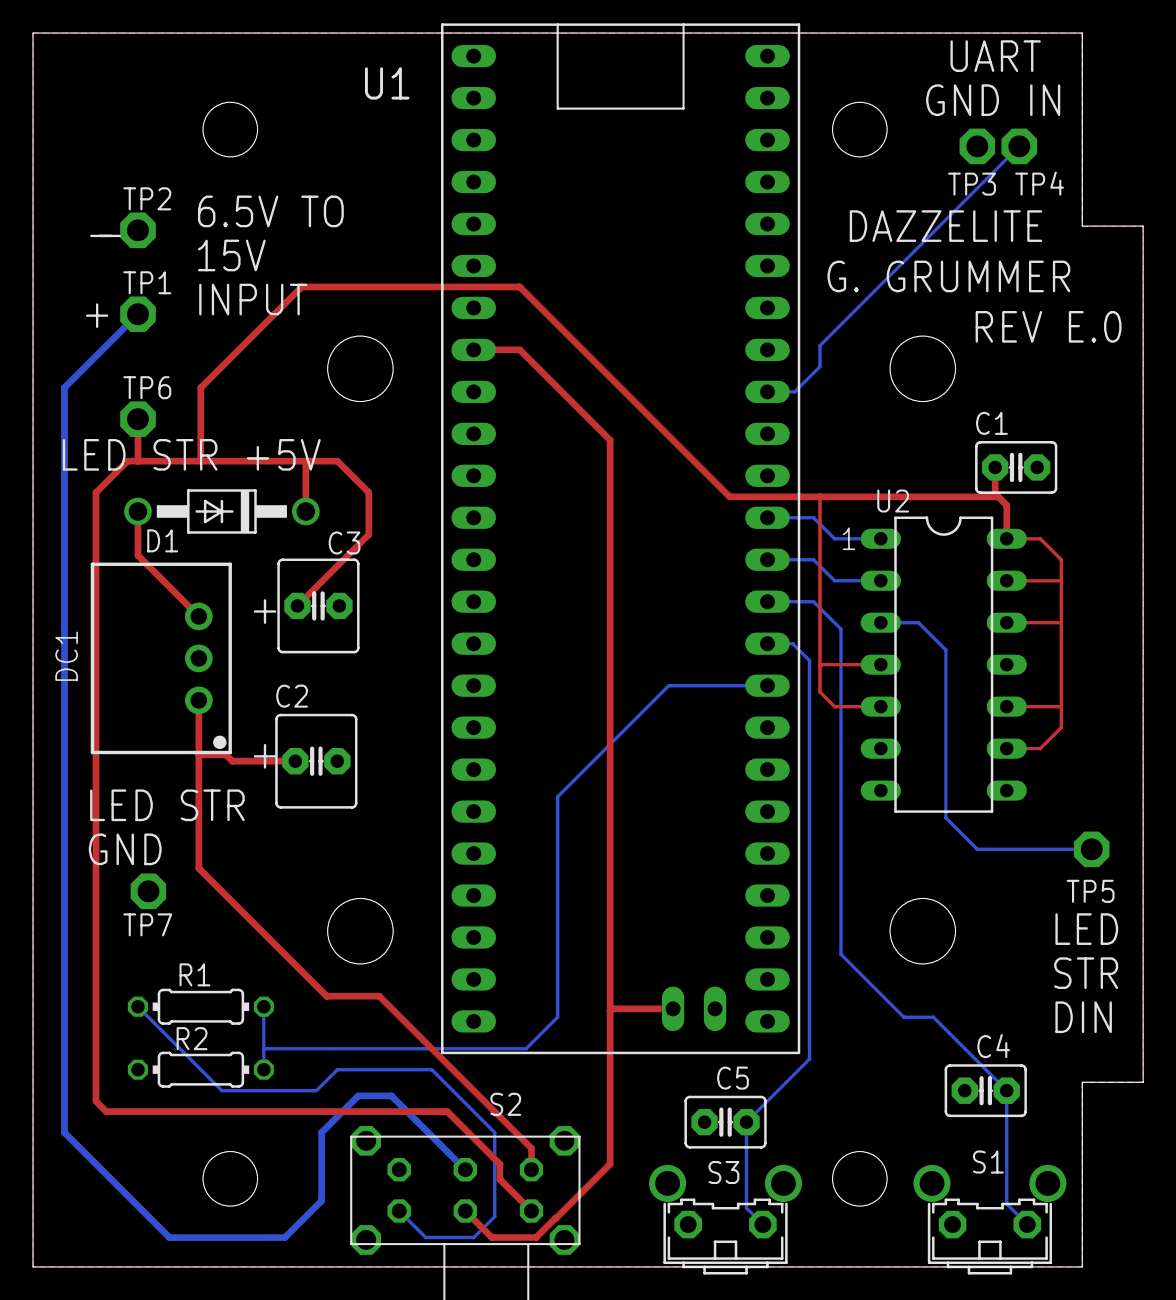
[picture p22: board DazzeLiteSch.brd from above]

Board: 2 copper layers, 67.2 x 74.7 mm, 21 parts (0 on the bottom side), 14 nets.

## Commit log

2021-02-08 Rev E Changes
    New board rev includes new FPGA pinout and fix to power up detection circuit.
    Added functionality to chase module. One can now select step size.
    [CaseCutOuts0p3.xlsx, DazzeLiteSch.brd, DazzeLiteSch.sch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]
2021-02-15 Update DazzelitePL.xlsx
    Reduced PCB cost.
    [DazzelitePL.xlsx]
2021-02-15 Corrected a few part numbers
    [DazzeLiteSch.brd, DazzeLiteSch.sch]
2021-02-18 Many changes
    Added schematic for a scaled down breadboard design.
    Updated instruction memories to block diagram.
    Moved parts list to EAGLE directory.
    Removed case cutout spreadsheet, will be replaced by assembly document.
    [CaseCutOuts0p3.xlsx, DazzelitePL.xlsx]
2021-02-20 Added documentation.
    The "Assembly Instructions" and "Installation and Setup" manuals are in good shape. The "User's Manual" need a new link to the yet to be produced video.
2021-02-27 Update Dazzelite Assembly Instructions.pdf
    Added/updated some pictures.
2021-03-10 Update DazzelitePL.xlsx
    Changed 9V battery connector to one where the wires come out the side. This makes it easier to get the battery in & out.
    [DazzelitePL.xlsx]
